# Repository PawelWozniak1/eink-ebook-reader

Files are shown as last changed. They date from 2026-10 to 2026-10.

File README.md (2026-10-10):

# 📖 DIY E-Paper E-Book Reader

🇬🇧 **English** · 🇵🇱 [Polski](README.pl.md)



An e-book reader built from scratch. A Python pipeline prepares the books, firmware with its own page layout engine runs on an ESP32-S3, and the case was designed in OpenSCAD and 3D-printed.

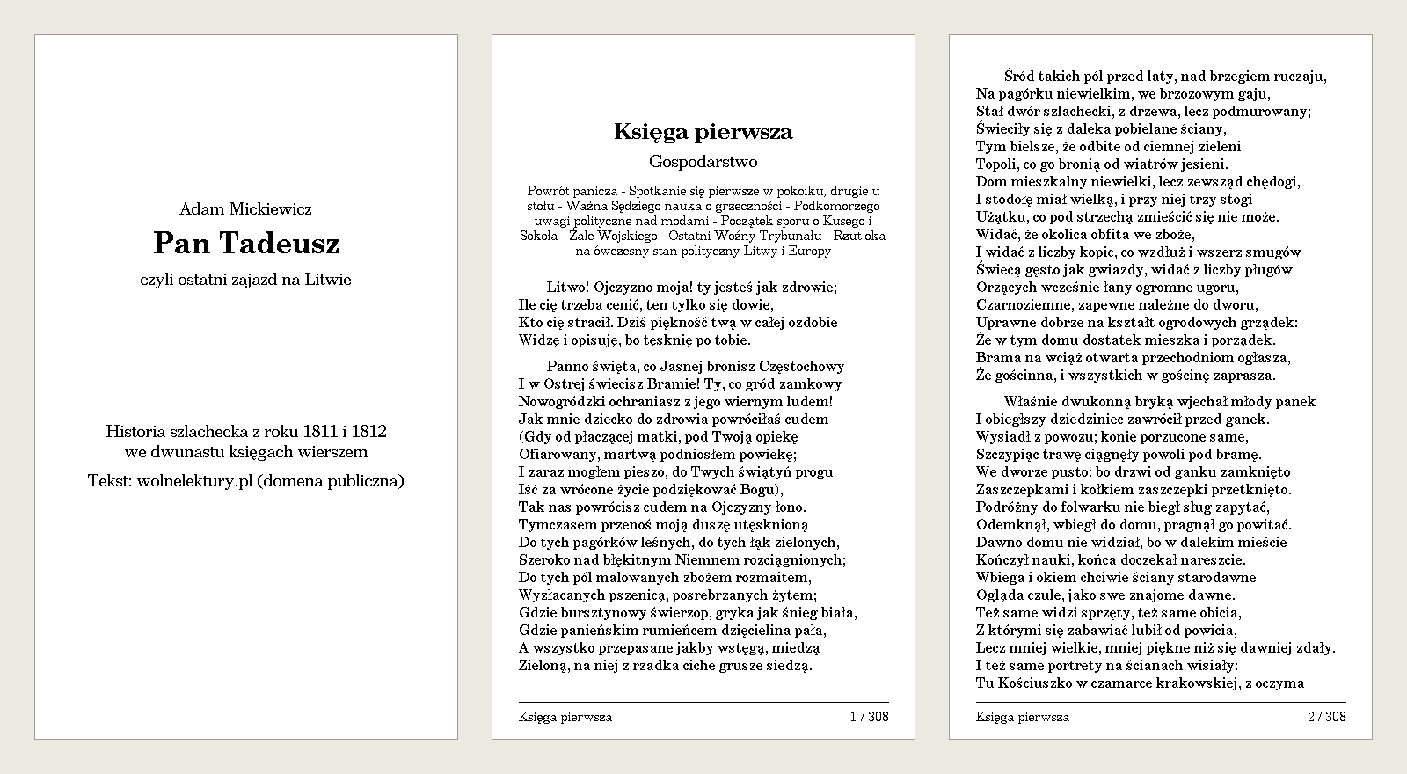
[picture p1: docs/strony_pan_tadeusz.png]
Pages rendered by the simulator


<sub>Pages rendered by the Python simulator with the device's own bitmap fonts: title page, a chapter opening with subtitle and summary, and a regular page with footer.</sub>

---

## ✨ Features

- **Real typesetting:** justified prose paragraphs, indentation, wrapping of over-long verse lines, preserved stanza breaks in poetry
- **Automatic prose vs. poetry detection** based on line-length statistics
- **Chapters and table of contents:** every chapter starts on a new page, navigated with a joystick
- **4 font sizes** with full Polish character support; after a size change the reader stays at the same place in the text
- **Bookmarks:** the reader remembers your position in every book, even after a power cut
- **Power saving:** deep sleep after 30 minutes of inactivity or on a long button press; waking up goes straight back to the last page
- **Battery status** in the library menu: percentage, or a lightning bolt while charging; automatic sleep when the battery runs flat
- **Wi-Fi mode:** a web page for uploading and deleting books and for over-the-air (OTA) firmware updates, no cable needed
- **Captive portal:** with no home network available, the reader starts its own access point and phones open its page automatically
- **Bonus: tic-tac-toe** for two phones, with the board drawn on the e-paper 🎮

---

## 🐍 Python: book preparation pipeline

[`przygotuj_ksiazke.py`](tools/przygotuj_ksiazke.py) ("prepare book") converts raw TXT files from [Wolne Lektury](https://wolnelektury.pl) (a Polish public-domain library) into a lightweight format the reader understands.

```bash
python tools/przygotuj_ksiazke.py
```
```
Pan Tadeusz: 10742 linii, 479913 bajtów -> books/prepared/pan_tadeusz.txt
Treny: 699 linii, 28279 bajtów -> books/prepared/treny.txt
```

What the script does:

| Step | How |
|---|---|
| Strips the license footer | finds the `-----` separator |
| Detects the books (chapters) of *Pan Tadeusz* | a regular expression for "Księga pierwsza … dwunasta" and "Epilog" |
| Tells a chapter subtitle from its summary | heuristic based on line length and indentation |
| Assembles *Treny* from 20 separate files | `pathlib.glob` plus splitting each heading into title and subtitle |
| Generates a title page | a function taking `*args` for any number of subtitles |
| Adapts the text to microcontroller fonts | a replacement table for typographic characters (`—`, `„`, `…`) |
| Normalizes whitespace | collapses blank lines, forces LF line endings, UTF-8 |

Adding a new book takes one entry in the `KSIAZKI` list and a function that returns a list of lines.

The same logic is also ported to JavaScript on the reader's web page ([`strona.h`](firmware/czytnik/strona.h)), so a plain TXT file can be uploaded straight from a phone. The Python script handles the unusual structure of *Pan Tadeusz* and *Treny* better.

### Book file format

The first line is a header. In the text after it, the first byte of each line can be a control marker:

```
#CZYTNIK|Pan Tadeusz|Adam Mickiewicz
\004Pan Tadeusz
\001Księga pierwsza
\002Gospodarstwo
\003Powrót panicza - Spotkanie się pierwsze w pokoiku, drugie u stołu - ...

    Litwo! Ojczyzno moja! ty jesteś jak zdrowie:
```

| Marker | Meaning |
|---|---|
| `\001` | chapter title (always starts a new page) |
| `\002` | chapter subtitle |
| `\003` | chapter summary (smaller font, wrapped) |
| `\004` | large title (title page) |
| `\005` | centered text |
| `\006` | prose paragraph (indented and justified) |
| *(none)* | line of verse |
| empty line | gap between stanzas |

The format is deliberately simple. The reader doesn't have to parse HTML or EPUB, and a single pass over the file is enough to find the chapters and split the text into pages.

---

## 🖥️ Python: reader simulator

[`tools/symulator/`](tools/symulator/) renders a book exactly as the device shows it and saves the pages as PNG files. It is a Python port of the firmware's layout engine, so you can check how a book looks without flashing anything.

```bash
pip install -r requirements.txt
python tools/symulator/czytnik.py books/prepared/pan_tadeusz.txt -s 0 1 2 -m preview.png
```
```
Pan Tadeusz: 308 stron, 13 rozdziałów, wiersz, czcionka średnia
-> preview.png
```

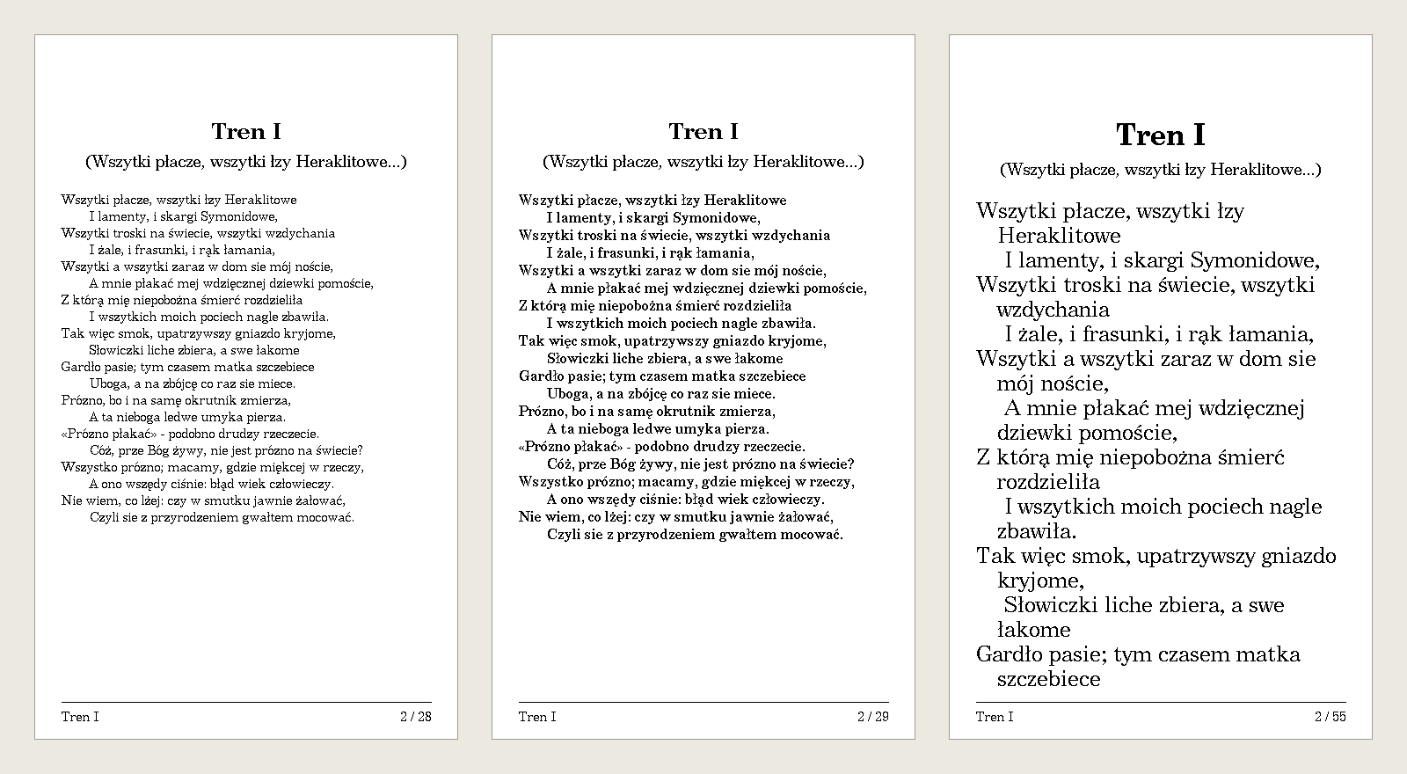
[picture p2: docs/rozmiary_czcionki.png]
The same page at three font sizes


<sub>Tren I at the small, medium and extra-large font sizes. Over-long verse lines wrap with a hanging indent, and the page count in the footer changes with the font size.</sub>

How it works:

- **u8g2 font decoder** ([`u8g2_font.py`](tools/symulator/u8g2_font.py)). The fonts in the firmware are bitmap fonts stored as bit-level run-length encoded byte arrays inside a C source file. The decoder parses C string literals (octal and hex escapes), reads the 23-byte header, finds glyphs via the ASCII lists and the Unicode jump table, and unpacks the RLE bitmaps. Text width follows the library's quirks exactly, e.g. the last glyph counts with its bitmap width, not its advance.
- **Layout engine port** ([`czytnik.py`](tools/symulator/czytnik.py)). The code mirrors `ulozStrone`, `podzielNaStrony` and `rysujStrone` from the firmware and works on UTF-8 byte offsets like the C++ code does. Bookmark positions saved by the device therefore point at the same place in the simulator.
- **CLI** built with `argparse`: pick pages, a font size, an output folder, or a single side-by-side montage.
- **Tests** ([`tests/`](tests/)) run on GitHub Actions. They cover the bit reader, the C literal parser, Polish glyphs in every font, text measurement, and pagination invariants: pages cover the whole text, every chapter starts a new page, and a larger font gives more pages.

The images in this README are generated with `python tools/symulator/zrzuty_do_readme.py`.

---

## 🔌 Firmware

The Arduino code lives in [`firmware/czytnik/`](firmware/czytnik/), about 1,900 lines of C++, HTML and JavaScript:

| File | What's inside |
|---|---|
| [`czytnik.ino`](firmware/czytnik/czytnik.ino) | main loop, buttons, block cache, layout engine, justification, menu, table of contents, bookmarks, deep sleep |
| [`bateria.ino`](firmware/czytnik/bateria.ino) | battery voltage via ADC, percentage from a LiPo discharge curve, charger detection, deep-discharge protection |
| [`siec.ino`](firmware/czytnik/siec.ino) | Wi-Fi (home network or own access point), web server, book upload and delete, firmware upload, ArduinoOTA, captive portal |
| [`strona.h`](firmware/czytnik/strona.h) | the upload web page (HTML/CSS/JS in `PROGMEM`), including the JS port of the book preparation |
| [`gra.ino`](firmware/czytnik/gra.ino) / [`gra.h`](firmware/czytnik/gra.h) | tic-tac-toe for two phones: game state, player slots with timeouts, board drawn on the e-paper |

---

## 🏗️ Architecture

```mermaid
flowchart LR
    WL["Wolne Lektury TXT"] --> PY["przygotuj_ksiazke.py"]
    WL --> JS["reader web page<br/>JS preparation"]
    PY --> TXT["CZYTNIK format"]
    TXT -->|"Wi-Fi upload"| FS[("LittleFS<br/>flash storage")]
    JS --> FS
    FS --> CACHE["block cache 8×4 KB"]
    CACHE --> LAYOUT["page layout engine"]
    LAYOUT --> EPD["7.5 inch e-paper"]
    JOY["joystick + SET/RST"] --> UI["menu / reading / contents"]
    UI --> LAYOUT
    NVS[("Preferences<br/>bookmarks")] <--> UI
```

### Firmware highlights

- **Books larger than RAM:** *Pan Tadeusz* is about 480 KB, so the text is read from flash in 4 KB blocks and the 8 most recently used blocks are kept in an LRU cache.
- **Custom text measurement:** asking the graphics library to measure every word was too slow, so glyph advance widths (up to U+017F, which covers all Polish letters) are computed once and cached for each font.
- **Re-pagination:** when the font size changes, the whole book is split into pages again and the reader returns to the same position in the text, not the same page number.
- **Bookmarks in NVS:** `Preferences` keys are limited to 15 characters, so file names are hashed with FNV-1a. Bookmarks from an older firmware version are migrated automatically.
- **Safe uploads:** an uploaded file is written under a temporary name and only swapped in once complete, so an interrupted upload never corrupts an existing book. File names are sanitized to `a-z0-9_-`.
- **E-paper refresh strategy:** fast partial refresh when turning pages and a full refresh every 20 pages to clear ghosting.

---

## 🔧 Hardware

| Part | Model |
|---|---|
| Microcontroller | ESP32-S3-DevKitC-1 |
| Display | Waveshare e-Paper 7.5" 800×480 (GDEY075T7) + HAT |
| Controls | 5-way joystick + SET + RST |
| Power | LiPo 523450 1000 mAh + TP4056 USB-C charger + Pololu S7V8F3 (3.3 V buck-boost) |

<details>
<summary>Wiring</summary>

| Signal | GPIO |
|---|---|
| e-paper CS / DC / RST / BUSY | 8 / 9 / 10 / 4 |
| e-paper SCK / MOSI | 18 / 17 |
| UP / DWN / LFT / RHT / MID | 5 / 6 / 7 / 15 / 16 |
| SET / RST | 21 / 47 |
| battery voltage (100k/100k divider from TP4056 OUT+) | 1 |
| charger present (100k/100k divider from TP4056 IN+) | 2 |

Buttons pull to GND (internal pull-ups). Newer HATs have a 9th pin, PWR: it goes to 3V3 together with VCC, so the display is always powered.

Power path: battery → TP4056 (B+/B−) → OUT+/OUT− → Pololu S7V8F3 (VIN/GND) → VOUT to the ESP32 **3V3** pin. The 5V pin stays unconnected. Unplug the battery before flashing over USB.

The battery dividers are optional: without them the reader works, it just doesn't show the battery level. How to build them (in Polish): [`docs/dzielnik_baterii.md`](docs/dzielnik_baterii.md).
</details>

<details>
<summary>Layout inside the case</summary>

The reader is held in portrait. Positions are given from the front, as you look at the text:

| Part | Where |
|---|---|
| joystick (with SET and RST) | in the back cover, top left, stick facing out |
| TP4056 | right edge, top, USB-C port in the right wall |
| Pololu converter | lying flat below the charger, pins towards the middle |
| battery | top, between the joystick and the charger |
| HAT | right edge, level with the FPC ribbon (middle of the panel's right edge) |
| ESP32 | bottom centre, USB ports in the bottom wall, antenna up |
| dividers | on a small board right next to GPIO1 and GPIO2 |

The button wires run down the left edge as one bundle and pass under the ESP board to its right header, so the ESP sits on its headers with 2–3 mm of clearance. Routing rules and the full connection table (in Polish): [`docs/okablowanie.md`](docs/okablowanie.md).
</details>

### Wiring

Front view, reader in portrait, display drawn as if transparent. Routing rules and the connection table (in Polish): [`docs/okablowanie.md`](docs/okablowanie.md).

<p align="center">Board and wire layout, front view</p>

### Controls

| Button | Reading | Menu | Contents |
|---|---|---|---|
| UP / DWN | previous / next page | select book | select chapter |
| LFT | chapter start / previous chapter | last read book | back |
| RHT | next chapter | open | go to |
| MID | menu (hold: sleep) | open | go to |
| SET | table of contents | — | back |
| RST | font size | — | — |

---

## 🖨️ Case

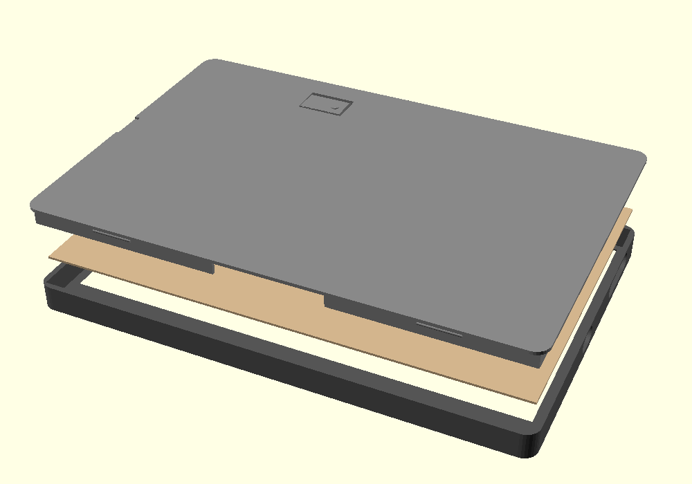
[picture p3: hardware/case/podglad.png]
Case preview (exploded view)


A parametric OpenSCAD design: [`czytnik_eink.scad`](hardware/case/czytnik_eink.scad). Every dimension is a variable: panel size, tolerances, positions of the battery, ESP32 and charger, the USB-C ports and the rear button. That makes it easy to adapt the case to a different display.

It prints as three parts: the front bezel, a support plate behind the panel and the back cover. Ready-made STL and OBJ files are included.

> The case design still follows the earlier electronics layout. The new one (joystick in the back cover, charging port in the right wall, ESP at the bottom) is described in [`docs/okablowanie.md`](docs/okablowanie.md).

---

## 🚀 Getting started

1. **Arduino IDE** with ESP32 support and the `GxEPD2` and `U8g2_for_Adafruit_GFX` libraries.
2. Board: *ESP32S3 Dev Module*. Pick a **Partition Scheme** with OTA and SPIFFS, e.g. *Default 4MB with spiffs (1.2MB APP/1.5MB SPIFFS)*.
3. Flash the sketch from [`firmware/czytnik/`](firmware/czytnik/).
4. Prepare the books: `python tools/przygotuj_ksiazke.py`. Optionally preview them with the simulator.
5. On the reader, choose **Wgraj książki (WiFi)** ("Upload books"), open the address shown on screen (or `http://czytnik.local`) and upload the files from `books/prepared/`.

Later firmware versions can be uploaded through the same page (a `.bin` file) or from the Arduino IDE over the network port.

---

## 📁 Project structure

```
├── books/
│   ├── source/                    # input: Wolne Lektury TXT (Pan Tadeusz, 20 Treny files)
│   └── prepared/                  # output: #CZYTNIK format, ready to upload
├── tools/
│   ├── przygotuj_ksiazke.py       # Python: source TXT -> reader format
│   ├── okablowanie.py             # generates docs/okablowanie.svg and .md
│   └── symulator/
│       ├── czytnik.py             # layout engine port + CLI
│       ├── u8g2_font.py           # u8g2 bitmap font decoder
│       ├── fonty/                 # the 6 fonts used by the firmware
│       └── zrzuty_do_readme.py    # regenerates docs/*.png
├── firmware/czytnik/              # Arduino sketch (open czytnik.ino)
│   ├── czytnik.ino                # main program: layout, menu, bookmarks, sleep
│   ├── bateria.ino                # battery and charging status
│   ├── siec.ino                   # Wi-Fi, web server, uploads, OTA, captive portal
│   ├── strona.h                   # web page (HTML/CSS/JS in PROGMEM)
│   └── gra.ino / gra.h            # tic-tac-toe
├── hardware/case/                 # OpenSCAD source, preview, stl/, obj/
├── tests/                         # unittest, run on GitHub Actions
└── docs/                          # README images, wiring drawing, divider guide
```

The code and its comments are in Polish.

---

## 🛠️ Tech stack

**Python** (pathlib, re, Pillow, argparse, dataclasses, unittest) · **GitHub Actions** · **C++ / Arduino** (ESP32-S3, LittleFS, NVS, deep sleep) · **GxEPD2, U8g2** · **HTML / CSS / JavaScript** · **WebServer, DNSServer, mDNS, ArduinoOTA** · **OpenSCAD** · 3D printing

## 📜 License and sources

The texts of *Pan Tadeusz* (Adam Mickiewicz) and *Treny* (Jan Kochanowski) come from [Wolne Lektury](https://wolnelektury.pl) and are in the public domain.

The bitmap fonts in `tools/symulator/fonty/` come from the [u8g2](https://github.com/olikraus/u8g2) project, which redistributes them under their original X11/Adobe licenses.

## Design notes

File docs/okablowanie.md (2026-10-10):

# Okablowanie i rozmieszczenie płytek

Czytnik w pionie, widok od przodu, tak jak patrzysz na tekst. Ekran jest narysowany jak przezroczysty, więc widać przez niego płytki leżące za nim. Przy składaniu od tyłu lewa i prawa strona się zamieniają. Skala: 1 jednostka = 1 mm.

Rozmieszczenie płytek i przewodów

Wymiary płytek są rzeczywiste: ekran 111×170 mm, ESP32-S3-DevKitC-1 25,5×63 mm, HAT 30×65 mm, LiPo 523450 34×50 mm, TP4056 17×28 mm, Pololu S7V8F3 11,4×15,2 mm. Wnętrze obudowy: ok. 115×174 mm. Kolejność pinów na module joysticka i padów na TP4056 zależy od wersji płytki, więc sprawdź napisy na swoich.

## Zasady prowadzenia przewodów

Numery odpowiadają znacznikom na rysunku.

1. **Gniazdo ładowania w prawej ściance, u góry.** TP4056 leży poziomo, gniazdem USB-C równo ze ścianką. Pod nim, między ładowarką a HAT-em, leży przetwornica, pinami w stronę środka. Przewody z niej schodzą szczeliną między baterią a HAT-em. Jeśli chcesz widzieć diodę ładowania, zrób przy gnieździe mały otwór.
2. **ESP na dole, antena do góry.** Gniazda USB ESP są przy dolnej ściance. Możesz zrobić otwór na gniazdo UART i wgrywać program kablem bez rozkręcania, ale zawsze najpierw odłącz baterię. Który port jest który, sprawdź po napisach na płytce. Nad anteną nie prowadź przewodów.
3. **Bateria osobno, z luzem.** Podłóż i przykryj ją taśmą kaptonową. Mocuj taśmą dwustronną, nie klejem na gorąco. Zostaw 1–2 mm luzu, bo LiPo lekko puchnie z wiekiem.
4. **Taśmę FPC zaginaj łagodnie.** Wychodzi ze środka prawej krawędzi matrycy i wraca na tył do HAT-a, którego środek jest na tej samej wysokości. Zrób łuk, nie ostre zagięcie.
5. **Dzielniki przy samym ESP.** Krótkie mają być przewody do GPIO1 i GPIO2, a długie mogą być wejścia z TP4056. Jak zbudować płytkę: [dzielnik_baterii.md](dzielnik_baterii.md).
6. **Przyciski jednym pasem wzdłuż lewej krawędzi.** SET, RST i COM dochodzą do lewej listwy ESP, a pięć kierunków przechodzi pod płytką ESP do prawej listwy (na rysunku przyciemnione). ESP stoi więc na listwach z 2–3 mm prześwitu. Białe znaczniki to miejsca na opaskę albo kroplę kleju.
7. **Joystick w tylnej klapce.** Moduł przyklej albo przykręć od środka, grzybkiem na zewnątrz, i wytnij otwór trochę większy od grzybka. Na SET i RST zrób małe otwory albo naciskaj je wykałaczką. Piny są na krótszej krawędzi modułu, ułóż ją w dół.

## Przewody

- **Zasilanie** (bateria → TP4056 → Pololu → ESP): silikonowy 24 AWG. Przy nadawaniu Wi-Fi ESP32 pobiera chwilowo ok. 0,5 A.
- **Sygnały** (przyciski, dzielniki): silikonowy 28–30 AWG albo kynar.
- **Ekran:** oryginalny kabelek PH2.0 z HAT-a, od strony ESP obcięty i przylutowany. Wtyczki Dupont dodają ok. 10 mm wysokości.

## Tabela połączeń

| Skąd | Dokąd | Uwagi |
|---|---|---|
| **Zasilanie** | | |
| bateria + | TP4056 B+ |  |
| bateria − | TP4056 B− |  |
| TP4056 OUT+ | Pololu VIN |  |
| TP4056 OUT− | Pololu GND | masa całego układu to OUT−, nie B− |
| Pololu VOUT | ESP 3V3 | nie do pinu 5V |
| Pololu GND | ESP GND | skręć razem z przewodem 3V3 |
| **Pomiar baterii (opcjonalny)** | | |
| TP4056 OUT+ | dzielnik baterii | drugi przewód na ten sam pad OUT+ |
| TP4056 IN+ (5 V z USB) | dzielnik ładowarki | pad przy gnieździe USB-C |
| dzielnik baterii | GPIO1 |  |
| dzielnik ładowarki | GPIO2 |  |
| masa dzielników | ESP GND | ten sam pin GND co przetwornica |
| **Ekran (kabelek z HAT-a)** | | |
| HAT VCC | ESP GPIO3V3 |  |
| HAT GND | ESP GND |  |
| HAT DIN | ESP GPIO17 |  |
| HAT CLK | ESP GPIO18 |  |
| HAT CS | ESP GPIO8 |  |
| HAT DC | ESP GPIO9 |  |
| HAT RST | ESP GPIO10 |  |
| HAT BUSY | ESP GPIO4 |  |
| HAT PWR | ESP GPIO3V3 |  |
| **Przyciski (joystick w tylnej klapce)** | | |
| COM | ESP GND | wspólny przewód wszystkich przycisków |
| SET | ESP GPIO21 |  |
| RST | ESP GPIO47 |  |
| MID | ESP GPIO16 |  |
| RHT | ESP GPIO15 |  |
| LFT | ESP GPIO7 |  |
| DWN | ESP GPIO6 |  |
| UP | ESP GPIO5 |  |

---

Rysunek i ta strona są generowane przez [`tools/okablowanie.py`](../tools/okablowanie.py). Po zmianie układu uruchom `python tools/okablowanie.py`.

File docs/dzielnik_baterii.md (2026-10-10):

# Dzielnik napięcia do pomiaru baterii

Bez tej płytki czytnik działa normalnie, tylko nie pokazuje stanu baterii. Z nią w menu biblioteki widać procent naładowania albo błyskawicę podczas ładowania, a przy rozładowanej baterii (ok. 3,3 V) czytnik sam się usypia. Kod jest w [`firmware/czytnik/bateria.ino`](../firmware/czytnik/bateria.ino).

## Po co dzielnik

Bateria ma do 4,2 V, a USB 5 V. Wejście ADC w ESP32-S3 przyjmuje maksymalnie ok. 3,1 V, więc napięcie trzeba podzielić na pół. Robią to dwa jednakowe rezystory połączone szeregowo.

```
   wejście
      │
    [100k]   górny
      │
      ├──────► GPIO        połowa napięcia
      │
    [100k]   dolny
      │
     GND
```

Potrzebne są dwa takie dzielniki:

| Dzielnik | Wejście | Wyjście | Co mierzy |
|---|---|---|---|
| bateria | TP4056 **OUT+** | **GPIO1** | napięcie baterii (1,6–2,1 V na pinie) |
| ładowarka | TP4056 **IN+** (5 V z USB) | **GPIO2** | czy ładowarka jest wpięta (ok. 2,5 V albo 0 V) |

## Części

- 4 rezystory 100 kΩ, 1/4 W, THT. Pasuje też inna wartość w zakresie ok. 47k–470k, byle w parze były dwie jednakowe sztuki. Przy rezystorach 5% kup 8 sztuk i dobierz pary multimetrem.
- Kondensator ceramiczny 100 nF (nadruk `104`), uspokaja odczyt ADC.
- Kawałek płytki uniwersalnej, raster 2,54 mm, ok. 2×2 cm (najlepiej dwustronnej, z metalizowanymi otworami).

Nie używaj 1 kΩ ani innych małych wartości. Dzielnik baterii pobiera prąd cały czas, także w uśpieniu: 2×100 kΩ to ok. 20 µA, a 2×1 kΩ to ok. 2 mA, które rozładowałyby baterię w kilka tygodni.

## Ułożenie na płytce

```
   5V (z IN+)          VBAT (z OUT+)
       │                    │
     [R3]                 [R1]
       │                    │
       ●──┐              ┌──●──[C]──┐
       │  │              │  │       │
     [R4] │              │ [R2]     │
       │  │              │  │       │
   ····●··│··············│··●·······●···· GND (od spodu płytki) ──► GND ESP
          ▼              ▼
        GPIO2          GPIO1
```

1. Wlutuj R1 nad R2 i R3 nad R4, w dwóch kolumnach. Wspólna nóżka w każdej parze to środek dzielnika.
2. Kondensator wlutuj między środek dzielnika baterii (R1/R2) a masę. Nie ma polaryzacji.
3. Dolne końce R2, R4 i kondensatora połącz razem jako masę. Poprowadź ją od spodu płytki, wtedy nie krzyżuje się z odczepami do GPIO.
4. Płytkę przyklej tuż obok pinów 1 i 2 ESP. Przewody do GPIO mają być krótkie, bo rezystory 100 kΩ mają dużą impedancję i długi przewód zbiera zakłócenia. Długie mogą być przewody wejściowe z TP4056.

## Sprawdzenie przed podłączeniem do ESP

Najpierw przylutuj tylko wejścia i masę, a przewodów do GPIO jeszcze nie. Zmierz multimetrem względem GND:

- środek R1/R2: połowa napięcia baterii, czyli ok. 1,6–2,1 V,
- środek R3/R4: ok. 2,5 V przy wpiętej ładowarce, 0 V bez niej.

Jeśli zobaczysz ok. 4 V albo 5 V, coś jest źle połączone. Takie napięcie spali pin ESP, więc najpierw znajdź błąd. Gdy wartości się zgadzają, dolutuj przewody do GPIO1 i GPIO2.

## Pierwsze uruchomienie

Wgraj program i wejdź do menu. Obok napisu „Biblioteka” powinna być ikona baterii z procentem. Po wpięciu ładowarki ekran sam się odświeży i pojawi się błyskawica z napisem `ładuje`, a po naładowaniu `pełna`.

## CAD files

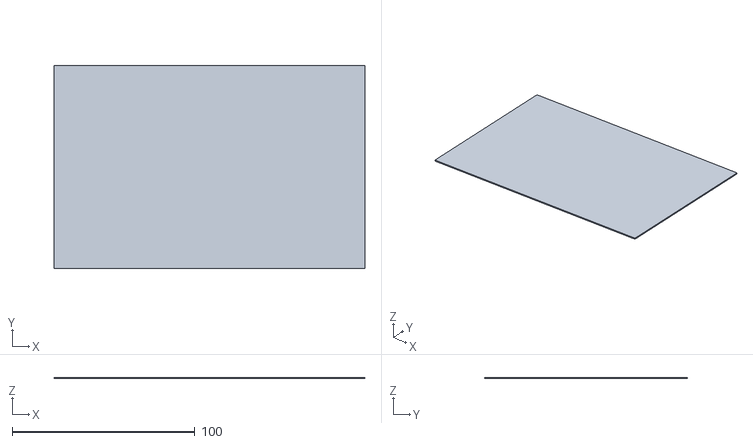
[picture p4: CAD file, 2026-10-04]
hardware/case/stl/czytnik_plytka.stl
170.0 x 111.0 x 0.8

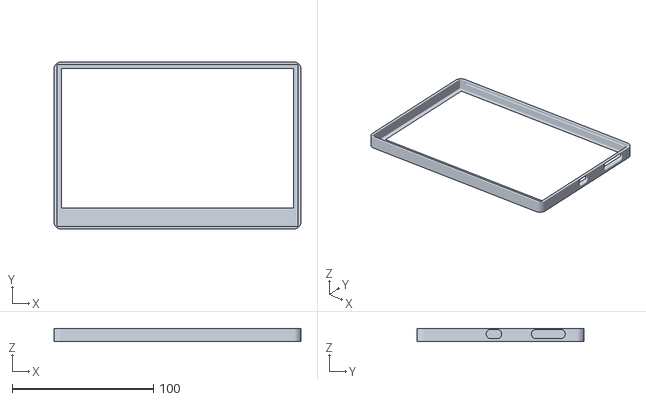
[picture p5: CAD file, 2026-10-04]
hardware/case/stl/czytnik_przod.stl
174.8 x 118.3 x 9.40

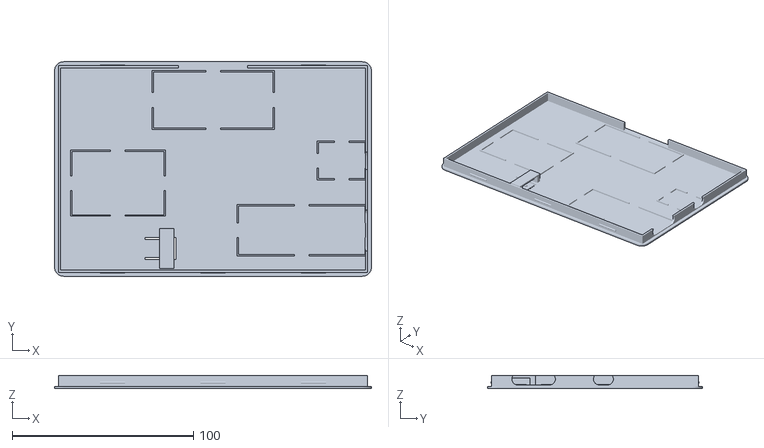
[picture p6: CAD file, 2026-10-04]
hardware/case/stl/czytnik_klapka.stl
174.8 x 118.3 x 7.20

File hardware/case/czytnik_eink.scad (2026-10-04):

// ============================================================
//  Obudowa czytnika DIY  —  e-Paper 7,5" Waveshare 13504 (800x480)
//  ESP32-S3-DevKitC-1, LiPo 523450, TP4056 USB-C, 1 przycisk z tylu
//  Jednostki: mm
//
//  Uklad wspolrzednych: widok OD PRZODU (od strony ekranu),
//  x w prawo, y w gore, z=0 to przednia powierzchnia, z rosnie do tylu.
//  Wszystkie pozycje czesci podajesz wiec tak, jak widzisz je przez ekran.
//
//  Czesci:
//    "front" – przednia ramka ze sciankami (drukuj przodem do stolu)
//    "mid"   – plytka podporowa za panelem (0,8 mm)
//    "lid"   – tylna klapka z rantem, przyciskiem i gniazdami na czesci
//    "all"   – podglad zlozenia,  "exploded" – podglad rozlozony
// ============================================================

part = "exploded"; // [front, mid, lid, all, exploded]

/* [Panel e-ink — ZMIERZ swoj egzemplarz!] */
panel_w   = 170.2;
panel_h   = 111.2;
panel_t   = 1.2;
aa_w      = 163.2;   // obszar aktywny
aa_h      = 97.92;
aa_left   = 3.5;     // od lewej krawedzi panelu do obszaru aktywnego
aa_bottom = 10.58;   // od dolnej krawedzi (strona tasmy FPC) do obszaru aktywnego
fpc_center_x = 85.1; // srodek tasmy FPC liczony od lewej krawedzi panelu
fpc_w     = 32;      // szerokosc tasmy + zapas

/* [Obudowa] */
wall      = 2.0;   // grubosc scianek bocznych
clr       = 0.3;   // luz wokol panelu
fpc_gap   = 2.5;   // dodatkowe miejsce na zagiecie tasmy FPC (dol)
front_t   = 1.2;   // grubosc przodu (ramki)
pocket_t  = 1.4;   // gniazdo na panel (panel 1,2 + luz)
mid_t     = 0.8;   // plytka podporowa
cav       = 6.0;   // wysokosc komory na elektronike
back_t    = 1.2;   // tylna scianka
corner_r  = 5;
fit       = 0.15;  // luz pasowania rantu klapki
rim_t     = 1.2;   // grubosc rantu klapki
win_margin= 0.4;   // okno troche wieksze niz obszar aktywny
bevel     = 1.0;   // fazowanie okna od przodu

/* [Przycisk z tylu] */
btn_x0    = 50;    // poczatek klawisza (zawias) — x
btn_cy    = 103;   // srodek klawisza — y
btn_len   = 16;
btn_w     = 10;
slot      = 1.0;   // szerokosc szczeliny wokol klawisza
sw_h      = 4.3;   // wysokosc tact switcha z popychaczem (6x6x4.3)
sw_size   = 6.2;

/* [Polozenie czesci (lewy dolny rog, widok od przodu)] */
hat_pos = [55, 6];    hat_size = [65, 30.2];
bat_pos = [10, 50];   bat_size = [50, 34];
tp_size = [25, 19];
esp_size= [69, 26];

$fn = 32;

// ---------- wartosci wyliczone ----------
iw = panel_w + 2*clr;
ih = panel_h + 2*clr + fpc_gap;
W  = iw + 2*wall;
H  = ih + 2*wall;
px = wall + clr;                 // panel – lewy dolny rog
py = wall + clr + fpc_gap;
z_mid = front_t + pocket_t;
z_cav = z_mid + mid_t;
z_lid = z_cav + cav;
T     = z_lid + back_t;
rim_in = wall + fit + rim_t;     // wewnetrzna krawedz rantu

esp_pos = [W - rim_in - 0.5 - esp_size[0], 80];
tp_pos  = [W - rim_in - 0.5 - tp_size[0], 45];

port_z  = 5.4;   // wysokosc srodka gniazd USB-C (od przodu)
ports = [ // [srodek y, dlugosc, wysokosc]
  [esp_pos[1] + esp_size[1]/2, 24, 6.5],   // ESP32 (oba gniazda)
  [tp_pos[1]  + tp_size[1]/2,  11, 6.5]    // TP4056
];

z_snap = z_cav + cav*0.65;

// przycisk – mostek z przelacznikiem
sw_x   = btn_x0 + btn_len - 4;
cb_z0  = z_cav + 0.1;
cb_z1  = cb_z0 + 1.2;
sw_tip = cb_z1 - 0.6 + sw_h;
pin_l  = z_lid - sw_tip - 0.2;
assert(pin_l >= 0.3, "Przelacznik za wysoki: zmniejsz sw_h albo zwieksz cav");
echo(str("Wymiary zewnetrzne: ", W, " x ", H, " x ", T, " mm"));
echo(str("Dlugosc popychacza: ", pin_l, " mm"));

// ---------- pomocnicze ----------
module rbox(x, y, w, h, r, z0, z1)
  translate([x, y, z0]) linear_extrude(z1 - z0)
    offset(r) offset(-r) square([w, h]);

module port_cuts() {
  for (p = ports) {
    yc = p[0]; l = p[1]; hh = p[2];
    hull() for (s = [-1, 1])
      translate([W - rim_in - 1, yc + s*(l - hh)/2, port_z])
        rotate([0, 90, 0]) cylinder(d = hh, h = rim_in + 2);
  }
}

module locator(pos, size, h = 1.0, t = 0.8, c = 0.4, gap = 8) {
  difference() {
    translate([pos[0]-c-t, pos[1]-c-t, z_lid-h])
      cube([size[0]+2*(c+t), size[1]+2*(c+t), h]);
    translate([pos[0]-c, pos[1]-c, z_lid-h-1])
      cube([size[0]+2*c, size[1]+2*c, h+2]);
    // przerwy na kable w polowie bokow
    translate([pos[0]+size[0]/2-gap/2, pos[1]-c-t-1, z_lid-h-1]) cube([gap, size[1]+2*(c+t)+2, h+2]);
    translate([pos[0]-c-t-1, pos[1]+size[1]/2-gap/2, z_lid-h-1]) cube([size[0]+2*(c+t)+2, gap, h+2]);
  }
}

// ---------- PRZOD ----------
module front() {
  wx = px + aa_left - win_margin;
  wy = py + aa_bottom - win_margin;
  ww = aa_w + 2*win_margin;
  wh = aa_h + 2*win_margin;
  difference() {
    rbox(0, 0, W, H, corner_r, 0, z_lid);
    translate([wall, wall, front_t]) cube([iw, ih, z_lid]);
    // okno z fazowaniem
    hull() {
      translate([wx, wy, front_t - 0.01]) cube([ww, wh, 0.1]);
      translate([wx - bevel, wy - bevel, -0.01]) cube([ww + 2*bevel, wh + 2*bevel, 0.01]);
    }
    // rowki zatrzaskow
    for (y = [wall, H - wall])
      translate([wall + 5, y, z_snap]) rotate([0, 90, 0]) cylinder(r = 0.65, h = iw - 10);
    port_cuts();
  }
}

// ---------- PLYTKA PODPOROWA ----------
module mid() {
  translate([px + 0.1, py + 0.1, z_mid]) cube([panel_w - 0.2, panel_h - 0.2, mid_t]);
}

// ---------- TYLNA KLAPKA ----------
module lid() {
  difference() {
    union() {
      // dno
      rbox(0, 0, W, H, corner_r, z_lid, T);
      // rant
      difference() {
        translate([wall + fit, wall + fit, z_cav]) cube([iw - 2*fit, ih - 2*fit, cav + 0.01]);
        translate([rim_in, rim_in, z_cav - 1]) cube([W - 2*rim_in, H - 2*rim_in, cav + 2]);
        // wyciecie na tasme FPC
        translate([px + fpc_center_x - (fpc_w + 6)/2, wall - 1, z_cav - 1])
          cube([fpc_w + 6, rim_t + fit + 2, cav + 1]);
      }
      // zatrzaski
      for (x = [25, W - 25 - 14])
        translate([x, wall + fit + 0.15, z_snap]) rotate([0, 90, 0]) cylinder(r = 0.6, h = 14);
      for (x = [25, W/2 - 7, W - 25 - 14])
        translate([x, H - wall - fit - 0.15, z_snap]) rotate([0, 90, 0]) cylinder(r = 0.6, h = 14);
      // gniazda na czesci
      locator(hat_pos, hat_size);
      locator(bat_pos, bat_size);
      locator(esp_pos, esp_size);
      locator(tp_pos,  tp_size);
      // mostek z przelacznikiem
      for (s = [-1, 1])
        translate([sw_x - 4, btn_cy + s*(btn_w/2 + slot + 3.5) - 1.5, cb_z0])
          cube([8, 3, z_lid - cb_z0]);
      translate([sw_x - 4, btn_cy - btn_w/2 - slot - 5, cb_z0])
        cube([8, btn_w + 2*slot + 10, cb_z1 - cb_z0]);
    }
    // szczelina w ksztalcie U wokol klawisza
    difference() {
      translate([btn_x0, btn_cy - btn_w/2 - slot, z_lid - 1])
        cube([btn_len + slot, btn_w + 2*slot, back_t + 2]);
      translate([btn_x0 - 1, btn_cy - btn_w/2, z_lid - 2])
        cube([btn_len + 1, btn_w, back_t + 4]);
    }
    // klawisz lekko wpuszczony (cienszy = latwiej sie ugina)
    translate([btn_x0, btn_cy - btn_w/2, T - 0.4]) cube([btn_len, btn_w, 1]);
    // gniazdo na przelacznik w mostku
    translate([sw_x - sw_size/2, btn_cy - sw_size/2, cb_z1 - 0.6]) cube([sw_size, sw_size, 1]);
    // otwory USB
    port_cuts();
    // wciecie do podwazania klapki
    translate([-1, H/2 - 6, T - 0.8]) cube([3, 12, 1]);
  }
  // popychacz + wyczuwalna kropka
  translate([sw_x, btn_cy, z_lid - pin_l]) cylinder(d = 3, h = pin_l + 0.01);
  translate([sw_x, btn_cy, T - 0.41]) cylinder(d = 3, h = 0.3);
}

// ---------- wybor ----------
if (part == "front") front();
else if (part == "mid") translate([0, 0, -z_mid]) mid();
else if (part == "lid") translate([0, H, T]) rotate([180, 0, 0]) lid(); // dnem do stolu
else if (part == "all") { color("#555") front(); color("tan") mid(); color("#888") lid(); }
else {
  color("#555") front();
  color("tan") translate([0, 0, 15]) mid();
  color("#888") translate([0, 0, 30]) lid();
}

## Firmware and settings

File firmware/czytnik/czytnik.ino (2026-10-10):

// Czytnik książek na e-papierze 7,5" + joystick
//
// Joystick (COM do GND), podczas czytania:
//   UP     - poprzednia strona
//   DWN    - następna strona
//   LFT    - początek rozdziału / poprzedni rozdział
//   RHT    - następny rozdział
//   MID    - menu z listą książek
//   MID przytrzymany - wyczyść ekran i uśpij (potem można odłączyć zasilanie)
//   SET    - spis treści
//   RST    - wielkość czcionki (mała / średnia / duża / bardzo duża)
//
// W spisie treści:
//   UP/DWN - wybór rozdziału
//   MID/RHT - przejdź do rozdziału
//   SET/LFT - wróć do czytania
//
// W menu:
//   UP/DWN - wybór książki
//   MID/RHT - otwórz książkę (ostatnia pozycja: tryb WiFi)
//   LFT    - wróć do ostatnio czytanej
//
// Po USPIJ_PO bez naciskania przycisków czytnik sam czyści ekran i zasypia.
// MID budzi go i otwiera książkę w tym samym miejscu.
//
// Książki są plikami w pamięci flash (LittleFS, katalog /k). Wgrywa się je przez WiFi:
// w menu wybierz "Wgraj książki (WiFi)" i otwórz w przeglądarce adres pokazany na ekranie.
// Tam można też wgrać nowy program (.bin) bez kabla. Kod WiFi jest w siec.ino.
//
// Stan baterii i ładowanie widać w menu (bateria.ino).
//
// Arduino IDE: Narzędzia > Partition Scheme musi mieć OTA i SPIFFS (tam trafia LittleFS),
// np. "Default 4MB with spiffs (1.2MB APP/1.5MB SPIFFS)". Schematy z FATFS albo "No OTA" nie zadziałają.

#include <GxEPD2_BW.h>
#include <U8g2_for_Adafruit_GFX.h>
#include <Preferences.h>
#include <LittleFS.h>
#include <vector>
#include <algorithm>
#include <driver/rtc_io.h>

// jeśli nie działa, wróć do starego sterownika: zamień oba GxEPD2_750_GDEY075T7 na GxEPD2_750_T7
GxEPD2_BW<GxEPD2_750_GDEY075T7, GxEPD2_750_GDEY075T7::HEIGHT> display(
  GxEPD2_750_GDEY075T7(/*CS=*/ 8, /*DC=*/ 9, /*RST=*/ 10, /*BUSY=*/ 4)
);
const char* WERSJA = "6 (bateria)";  // pokazywana w trybie WiFi i na stronie

U8G2_FOR_ADAFRUIT_GFX u8g2Fonts;
Preferences pamiec;

// --- przyciski ---
enum { GORA, DOL, LEWO, PRAWO, SRODEK, SET_, RST_, ILE_PRZYCISKOW };
const int pinyPrzyciskow[ILE_PRZYCISKOW] = {5, 6, 7, 15, 16, 21, 47};
const char* nazwyPrzyciskow[ILE_PRZYCISKOW] = {"UP", "DWN", "LFT", "RHT", "MID", "SET", "RST"};
bool byloWcisniete[ILE_PRZYCISKOW];
unsigned long wcisnietyOd[ILE_PRZYCISKOW];  // 0 = wciśnięcia nie widzieliśmy (np. trzymany przy starcie)
unsigned long ostatniaAktywnosc = 0;

// --- usypianie ---
const unsigned long DLUGIE_WCISNIECIE = 1500;          // ms przytrzymania MID, żeby uśpić
const unsigned long USPIJ_PO = 30UL * 60 * 1000;       // samo zasypia po 30 min bez przycisków

// --- układ strony (ekran pionowo 480 x 800) ---
const int MARGINES = 30;           // lewy margines
const int MARGINES_PRAWY = 30;     // prawy margines
const int GORA_TEKSTU = 40;        // gdzie zaczyna się tekst
const int MIEJSCE_NA_STOPKE = 52;  // wysokość stopki na dole
const int WCIECIE_SPACJI = 8;      // ile pikseli na jedną spację wcięcia
const int WCIECIE_ZAWINIECIA = 24; // wcięcie dalszej części zbyt długiego wersu
const int WCIECIE_AKAPITU = 24;    // wcięcie pierwszej linii akapitu prozy
const int PELNE_ODSWIEZENIE_CO = 20; // co ile stron pełne odświeżenie

// znaczniki z przygotuj_ksiazke.py (i ze strony w trybie WiFi)
// T_ZWYKLY to wers wiersza, T_AKAPIT to akapit prozy (wcięty i wyjustowany)
const char T_ZWYKLY = 0, T_KSIEGA = 1, T_PODTYTUL = 2, T_STRESZCZENIE = 3, T_TYTUL = 4, T_SRODEK = 5,
           T_AKAPIT = 6;

// --- książki w pamięci flash ---
// pierwsza linia pliku: #CZYTNIK|tytuł|autor, dalej tekst ze znacznikami
const char* NAGLOWEK = "#CZYTNIK|";

struct Ksiazka {
  String plik;       // nazwa pliku w /k
  String tytul;
  String autor;
  uint32_t dlugosc;  // długość tekstu (bez nagłówka)
};
std::vector<Ksiazka> ksiazki;

// co jest na ekranie
enum Ekran { CZYTANIE, MENU, WIFI, SPIS };
Ekran ekran = MENU;

// otwarta książka
int otwarta = -1;          // numer w 'ksiazki', -1 = żadna nie jest wczytana
String otwartyPlik;        // ostatnio czytana (zostaje też po zamknięciu)
File plikKsiazki;
uint32_t poczatekTekstu = 0;  // gdzie w pliku zaczyna się tekst (za nagłówkiem)
uint32_t DLUGOSC = 0;
bool proza = false;        // true = książka prozą (akapity), false = wierszem (wersy)
int dolTekstu;

std::vector<uint32_t> strony;          // gdzie w tekście zaczyna się każda strona
std::vector<uint32_t> ksiegi;          // gdzie w tekście zaczyna się każdy rozdział
std::vector<int> pierwszaStronaKsiegi; // numer strony, od której zaczyna się każdy rozdział
int obecna = 0;
int odswiezenOdPelnego = 0;

// menu
int wybrana = 0;
const int NA_EKRANIE = 6;  // ile pozycji menu mieści się na ekranie

// spis treści
int wybranyRozdzial = 0;
const int NA_EKRANIE_SPISU = 15;
const int WYS_SPISU = 42;  // wysokość pozycji w spisie

// wielkość czcionki (zapamiętywana, RST zmienia)
const uint8_t* const CZCIONKI_TEKSTU[] = {u8g2_font_ncenR10_te, u8g2_font_ncenR12_te,
                                          u8g2_font_ncenR14_te, u8g2_font_ncenR18_te};
const char* NAZWY_ROZMIAROW[] = {"mała", "średnia", "duża", "bardzo duża"};
const int ILE_ROZMIAROW = 4;
int rozmiar = 1;

// --- czytanie tekstu z pliku ---
// Cała książka nie mieści się w RAM, więc tekst jest czytany kawałkami (blokami),
// a kilka ostatnio używanych bloków trzymamy w pamięci.

const int BLOK = 4096, ILE_BLOKOW = 8;
struct Blok {
  int32_t nr;
  uint32_t uzyty;
  char dane[BLOK];
};
Blok bloki[ILE_BLOKOW];
uint32_t licznikUzyc = 0;

void wyczyscBufor() {
  for (Blok& b : bloki) { b.nr = -1; b.uzyty = 0; }
}

// znak nr 'i' otwartej książki (0 za końcem tekstu)
char znak(uint32_t i) {
  if (i >= DLUGOSC) return '\0';
  int32_t nr = i / BLOK;
  Blok* b = nullptr;
  Blok* najstarszy = &bloki[0];
  for (Blok& x : bloki) {
    if (x.nr == nr) { b = &x; break; }
    if (x.uzyty < najstarszy->uzyty) najstarszy = &x;
  }
  if (!b) {
    b = najstarszy;
    plikKsiazki.seek(poczatekTekstu + (uint32_t)nr * BLOK);
    plikKsiazki.read((uint8_t*)b->dane, BLOK);
    b->nr = nr;
  }
  b->uzyty = ++licznikUzyc;
  return b->dane[i % BLOK];
}

// --- lista książek ---

// czyta pierwszą linię pliku (najwyżej 300 znaków), "" gdy jej brak
String czytajNaglowek(File& f) {
  String s;
  while (f.available() && s.length() < 300) {
    char c = f.read();
    if (c == '\n') return s;
    s += c;
  }
  return "";
}

void wczytajListe() {
  ksiazki.clear();
  File katalog = LittleFS.open("/k");
  if (katalog) {
    for (File f = katalog.openNextFile(); f; f = katalog.openNextFile()) {
      String nazwa = f.name();
      if (f.isDirectory() || nazwa.startsWith(".")) continue;
      String n = czytajNaglowek(f);
      if (!n.startsWith(NAGLOWEK)) continue;
      int kreska = n.indexOf('|', strlen(NAGLOWEK));
      Ksiazka k;
      k.plik = nazwa;
      k.tytul = n.substring(strlen(NAGLOWEK), kreska < 0 ? n.length() : kreska);
      k.autor = kreska < 0 ? "" : n.substring(kreska + 1);
      k.dlugosc = f.size() - n.length() - 1;
      ksiazki.push_back(k);
    }
  }
  std::sort(ksiazki.begin(), ksiazki.end(),
            [](const Ksiazka& a, const Ksiazka& b) { return a.tytul < b.tytul; });
  Serial.printf("Ksiazek: %d\n", (int)ksiazki.size());
}

int indeksPliku(const String& plik) {
  for (int i = 0; i < (int)ksiazki.size(); i++) {
    if (ksiazki[i].plik == plik) return i;
  }
  return -1;
}

void zamknijKsiazke() {
  plikKsiazki.close();
  otwarta = -1;
}

// --- tekst ---

// Szerokości liter (o ile przesuwa się kursor) dla każdej czcionki, liczone raz i zapamiętywane.
// Mierzenie tekstu przez bibliotekę przy każdym słowie było bardzo wolne przy długich akapitach.
const int ILE_KODOW = 384;  // do U+017F - wszystkie polskie litery
struct Szerokosci {
  const uint8_t* czcionka;
  int8_t w[ILE_KODOW];  // -1 = jeszcze nie policzone
};
Szerokosci szerokosci[10];
int ileSzerokosci = 0;
const uint8_t* biezacaCzcionka = nullptr;
Szerokosci* biezaceSzer = nullptr;

void ustawFont(const uint8_t* f) {
  u8g2Fonts.setFont(f);
  biezacaCzcionka = f;
  biezaceSzer = nullptr;
}

void ustawCzcionke(char typ) {
  switch (typ) {
    case T_KSIEGA:       ustawFont(rozmiar == 3 ? u8g2_font_ncenB24_te : u8g2_font_ncenB18_te); break;
    case T_PODTYTUL:     ustawFont(u8g2_font_ncenR14_te); break;
    case T_STRESZCZENIE: ustawFont(rozmiar >= 2 ? u8g2_font_ncenR12_te : u8g2_font_ncenR10_te); break;
    case T_TYTUL:        ustawFont(u8g2_font_ncenB24_te); break;
    case T_SRODEK:       ustawFont(u8g2_font_ncenR14_te); break;
    default:             ustawFont(CZCIONKI_TEKSTU[rozmiar]); break;
  }
}

// zapisuje znak 'kod' w UTF-8, zwraca liczbę bajtów
int doUtf8(uint16_t kod, char* s) {
  if (kod < 0x80) { s[0] = kod; return 1; }
  if (kod < 0x800) { s[0] = 0xC0 | (kod >> 6); s[1] = 0x80 | (kod & 0x3F); return 2; }
  s[0] = 0xE0 | (kod >> 12); s[1] = 0x80 | ((kod >> 6) & 0x3F); s[2] = 0x80 | (kod & 0x3F);
  return 3;
}

// o ile pikseli przesuwa się tekst po znaku 'kod' w bieżącej czcionce
int przesuniecie(uint16_t kod) {
  // szerokość "Xl" minus "l" to dokładnie przesunięcie po X (biblioteka poprawia tylko ostatnią literę)
  auto zmierz = [](uint16_t k) {
    char s[5];
    int n = doUtf8(k, s);
    s[n] = 'l';
    s[n + 1] = '\0';
    return u8g2Fonts.getUTF8Width(s) - u8g2Fonts.getUTF8Width("l");
  };
  if (kod >= ILE_KODOW) return zmierz(kod);
  if (!biezaceSzer) {
    for (int i = 0; i < ileSzerokosci; i++) {
      if (szerokosci[i].czcionka == biezacaCzcionka) biezaceSzer = &szerokosci[i];
    }
    if (!biezaceSzer) {
      biezaceSzer = &szerokosci[ileSzerokosci < 10 ? ileSzerokosci++ : 0];
      biezaceSzer->czcionka = biezacaCzcionka;
      memset(biezaceSzer->w, -1, sizeof(biezaceSzer->w));
    }
  }
  if (biezaceSzer->w[kod] < 0) biezaceSzer->w[kod] = zmierz(kod);
  return biezaceSzer->w[kod];
}

// kod znaku UTF-8 zaczynającego się na pozycji 'q', w 'dl' zwraca liczbę bajtów
uint16_t kodZnaku(uint32_t q, int& dl) {
  uint8_t b = znak(q);
  if (b < 0x80) { dl = 1; return b; }
  if ((b & 0xE0) == 0xC0) { dl = 2; return ((b & 0x1F) << 6) | (znak(q + 1) & 0x3F); }
  if ((b & 0xF0) == 0xE0) {
    dl = 3;
    return ((b & 0x0F) << 12) | ((znak(q + 1) & 0x3F) << 6) | (znak(q + 2) & 0x3F);
  }
  dl = 1;
  return '?';
}

// kopiuje kawałek tekstu do bufora, żeby można go było zmierzyć albo narysować
const char* wytnij(uint32_t od, uint32_t doo) {
  static char bufor[1024];
  uint32_t n = min<uint32_t>(doo - od, sizeof(bufor) - 1);
  for (uint32_t i = 0; i < n; i++) bufor[i] = znak(od + i);
  bufor[n] = '\0';
  return bufor;
}

int szerokosc(uint32_t od, uint32_t doo) {
  return u8g2Fonts.getUTF8Width(wytnij(od, doo));
}

// zwraca, gdzie uciąć linię od 'p' do 'koniec', żeby zmieściła się w 'szer' pikselach
uint32_t dopasuj(uint32_t p, uint32_t koniec, int szer) {
  uint32_t ostatniaSpacja = 0;
  int w = 0;  // szerokość tekstu od 'p' do 'q'
  for (uint32_t q = p; q < koniec; ) {
    int dl;
    uint16_t kod = kodZnaku(q, dl);
    if (kod == ' ' && q > p) {
      if (w > szer) break;
      ostatniaSpacja = q;
    }
    w += przesuniecie(kod);
    q += dl;
  }
  if (w <= szer) return koniec;
  return ostatniaSpacja ? ostatniaSpacja : koniec;
}

// rysuje linię od 'od' do 'doo' rozciągniętą na 'szer' pikseli (odstępy między słowami równo powiększone)
void rysujWyjustowane(int x, int y, uint32_t od, uint32_t doo, int szer) {
  int slow = 0, szerSlow = 0;
  for (uint32_t p = od; p < doo; ) {
    uint32_t k = p;
    while (k < doo && znak(k) != ' ') k++;
    if (k > p) { slow++; szerSlow += szerokosc(p, k); }
    p = k + 1;
  }
  int luz = szer - szerSlow;
  int przerw = slow - 1;
  for (uint32_t p = od; p < doo; ) {
    uint32_t k = p;
    while (k < doo && znak(k) != ' ') k++;
    if (k > p) {
      int w = szerokosc(p, k);
      u8g2Fonts.drawUTF8(x, y, wytnij(p, k));
      if (przerw > 0) {
        int odstep = luz / przerw;  // reszta pikseli rozkłada się na kolejne przerwy
        luz -= odstep;
        przerw--;
        x += w + odstep;
      }
    }
    p = k + 1;
  }
}

// skraca tekst (UTF-8) w buforze, aż zmieści się w 'szer' pikselach, i dopisuje "..."
// bufor musi mieć 4 bajty zapasu
void skroc(char* s, int szer) {
  if (u8g2Fonts.getUTF8Width(s) <= szer) return;
  int n = strlen(s);
  while (n > 0) {
    do n--; while (n > 0 && (s[n] & 0xC0) == 0x80);  // nie tnij w środku polskiej litery
    while (n > 0 && s[n - 1] == ' ') n--;
    strcpy(s + n, "...");
    if (u8g2Fonts.getUTF8Width(s) <= szer) return;
  }
}

// Układa jedną stronę zaczynając od miejsca 'start' w tekście.
// Gdy rysuj == true, także ją rysuje. Zwraca miejsce, od którego zaczyna się następna strona.
uint32_t ulozStrone(uint32_t start, bool rysuj) {
  uint32_t p = start;
  int y = GORA_TEKSTU;
  bool pierwszaNaStronie = true;

  while (p < DLUGOSC) {
    uint32_t poczatekLinii = p;
    while (poczatekLinii > 0 && znak(poczatekLinii - 1) != '\n') poczatekLinii--;
    uint32_t koniecLinii = p;
    while (koniecLinii < DLUGOSC && znak(koniecLinii) != '\n') koniecLinii++;
    uint32_t nastepnaLinia = koniecLinii < DLUGOSC ? koniecLinii + 1 : DLUGOSC;

    char z = znak(poczatekLinii);
    char typ = (z >= T_KSIEGA && z <= T_AKAPIT) ? z : T_ZWYKLY;
    uint32_t tresc = poczatekLinii + (typ ? 1 : 0);
    // w prozie każda linia bez znacznika to akapit (plik przygotowany starszą wersją strony)
    if (typ == T_ZWYKLY && proza) typ = T_AKAPIT;
    bool kontynuacja = p > tresc;  // dalsza część zawiniętej linii
    uint32_t powrot = kontynuacja ? p : poczatekLinii;
    if (!kontynuacja) p = tresc;

    // każdy rozdział od nowej strony
    if (typ == T_KSIEGA && !pierwszaNaStronie) return powrot;

    // pusta linia = odstęp (na górze strony pomijany)
    if (koniecLinii == tresc) {
      if (typ == T_SRODEK) y += 150;  // odstęp na stronie tytułowej
      else if (!pierwszaNaStronie && !proza) y += 10;  // w prozie akapity bez odstępów
      p = nastepnaLinia;
      continue;
    }

    ustawCzcionke(typ);
    int wznios = u8g2Fonts.getFontAscent();
    int zejscie = u8g2Fonts.getFontDescent();  // ujemne
    int przed = (typ == T_KSIEGA && !kontynuacja) ? 60 : 0;
    bool wysrodkuj = typ != T_ZWYKLY && typ != T_AKAPIT;

    int wciecie = 0;
    if (typ == T_ZWYKLY) {
      if (kontynuacja) wciecie = WCIECIE_ZAWINIECIA;
      else while (znak(p) == ' ') { p++; wciecie += WCIECIE_SPACJI; }
    } else if (typ == T_AKAPIT && !kontynuacja) {
      wciecie = WCIECIE_AKAPITU;
      while (znak(p) == ' ') p++;
    }

    int szer = display.width() - MARGINES - MARGINES_PRAWY - wciecie;
    uint32_t koniecKawalka = dopasuj(p, koniecLinii, szer);

    int linia = y + przed + wznios;  // linia bazowa tekstu
    if (linia - zejscie > dolTekstu && !pierwszaNaStronie) return powrot;

    if (rysuj) {
      int x = MARGINES + wciecie;
      if (wysrodkuj) x = MARGINES + (display.width() - MARGINES - MARGINES_PRAWY - szerokosc(p, koniecKawalka)) / 2;
      // w prozie wszystkie linie poza ostatnią w akapicie są wyjustowane
      if (typ == T_AKAPIT && koniecKawalka < koniecLinii) rysujWyjustowane(x, linia, p, koniecKawalka, szer);
      else u8g2Fonts.drawUTF8(x, linia, wytnij(p, koniecKawalka));
    }

    y = linia - zejscie + (typ == T_STRESZCZENIE ? 3 : 5);
    pierwszaNaStronie = false;

    if (koniecKawalka >= koniecLinii) {
      if (typ == T_KSIEGA) y += 8;
      else if (typ == T_PODTYTUL) y += 12;
      else if (typ == T_STRESZCZENIE) y += 14;
      p = nastepnaLinia;
    } else {
      p = koniecKawalka;
      while (p < koniecLinii && znak(p) == ' ') p++;
    }
  }
  return DLUGOSC;
}

void podzielNaStrony() {
  unsigned long t = millis();
  strony.clear();
  ksiegi.clear();
  pierwszaStronaKsiegi.clear();

  // Proza czy wiersz? W prozie większość tekstu jest w długich liniach (akapitach),
  // w wierszu linie to krótkie wersy.
  uint32_t wszystkie = 0, wDlugich = 0, poczatekLinii = 0;
  for (uint32_t i = 0; i < DLUGOSC; i++) {
    char z = znak(i);
    if (z == T_KSIEGA && i == poczatekLinii) ksiegi.push_back(i);
    if (z == '\n' || i == DLUGOSC - 1) {
      uint32_t dl = i - poczatekLinii;
      wszystkie += dl;
      if (dl > 120) wDlugich += dl;
      poczatekLinii = i + 1;
    }
  }
  proza = wDlugich > wszystkie / 2;

  uint32_t p = 0;
  while (p < DLUGOSC) {
    strony.push_back(p);
    uint32_t nastepna = ulozStrone(p, false);
    if (nastepna <= p) break;  // zabezpieczenie przed zapętleniem
    p = nastepna;
  }
  if (strony.empty()) strony.push_back(0);  // pusta książka

  // rozdziały zawsze zaczynają się od nowej strony, więc wystarczy znaleźć stronę z tym samym początkiem
  for (uint32_t k : ksiegi) {
    int s = 0;
    while (s < (int)strony.size() - 1 && strony[s + 1] <= k) s++;
    pierwszaStronaKsiegi.push_back(s);
  }

  Serial.printf("Stron: %d, rozdzialow: %d, %s, liczenie trwalo %lu ms\n",
                (int)strony.size(), (int)ksiegi.size(), proza ? "proza" : "wiersz", millis() - t);
}

// numer rozdziału, w którym jest strona (-1 = strona tytułowa)
int ksiegaStrony(int strona) {
  int k = -1;
  for (int i = 0; i < (int)pierwszaStronaKsiegi.size(); i++) {
    if (pierwszaStronaKsiegi[i] <= strona) k = i;
  }
  return k;
}

// --- zakładki ---

// klucz w Preferences (najwyżej 15 znaków), więc zamiast nazwy pliku jej skrót
String kluczZakladki(const String& plik) {
  uint32_t h = 2166136261u;
  for (const char* c = plik.c_str(); *c; c++) {
    h ^= (uint8_t)*c;
    h *= 16777619u;
  }
  char k[12];
  snprintf(k, sizeof(k), "z%08lx", (unsigned long)h);
  return k;
}

uint32_t zakladka(int ksiazka) {
  return pamiec.getUInt(kluczZakladki(ksiazki[ksiazka].plik).c_str(), 0);
}

// zakładki ze starej wersji, w której książki były wkompilowane w program
void przeniesStareZakladki() {
  const char* stare[] = {"pan_tadeusz.txt", "treny.txt"};
  for (int i = 0; i < 2; i++) {
    String k = "k" + String(i);
    if (!pamiec.isKey(k.c_str())) continue;
    pamiec.putUInt(kluczZakladki(stare[i]).c_str(), pamiec.getUInt(k.c_str(), 0));
    pamiec.remove(k.c_str());
  }
  if (pamiec.isKey("ostatnia")) {
    int o = pamiec.getInt("ostatnia", -1);
    if (o >= 0 && o < 2) pamiec.putString("ostatniPlik", stare[o]);
    pamiec.remove("ostatnia");
  }
}

// --- rysowanie ---

void rysujStrone(int strona) {
  ulozStrone(strony[strona], true);

  if (strona == 0) return;  // strona tytułowa bez stopki

  int W = display.width();
  int H = display.height();
  display.drawLine(MARGINES, H - 42, W - MARGINES_PRAWY, H - 42, GxEPD_BLACK);

  u8g2Fonts.setFont(u8g2_font_ncenR10_te);
  char numer[32];
  snprintf(numer, sizeof(numer), "%d / %d", strona, (int)strony.size() - 1);
  int szerNumeru = u8g2Fonts.getUTF8Width(numer);
  u8g2Fonts.drawUTF8(W - MARGINES_PRAWY - szerNumeru, H - 20, numer);

  int k = ksiegaStrony(strona);
  if (k >= 0) {
    uint32_t od = ksiegi[k] + 1;
    uint32_t doo = od;
    while (doo < DLUGOSC && znak(doo) != '\n') doo++;
    // długi tytuł rozdziału (np. w Lalce) skracamy, żeby nie wszedł na numer strony
    char rozdzial[200];
    strncpy(rozdzial, wytnij(od, min<uint32_t>(doo, od + 190)), sizeof(rozdzial));
    skroc(rozdzial, W - MARGINES - MARGINES_PRAWY - szerNumeru - 20);
    u8g2Fonts.drawUTF8(MARGINES, H - 20, rozdzial);
  }
}

void naSrodku(const char* tekst, int y) {
  u8g2Fonts.drawUTF8((display.width() - u8g2Fonts.getUTF8Width(tekst)) / 2, y, tekst);
}

void rysujStopke(const char* tekst) {
  int H = display.height();
  display.drawLine(MARGINES, H - 42, display.width() - MARGINES_PRAWY, H - 42, GxEPD_BLACK);
  u8g2Fonts.setFont(u8g2_font_ncenR10_te);
  naSrodku(tekst, H - 20);
}

// tytuł rozdziału 'k' razem z podtytułem, np. "Księga pierwsza - Gospodarstwo"
// (bufor musi mieć 4 bajty zapasu na skroc())
void tytulRozdzialu(int k, char* bufor, int rozmiarBufora) {
  uint32_t od = ksiegi[k] + 1;
  uint32_t doo = od;
  while (doo < DLUGOSC && znak(doo) != '\n') doo++;
  String t = wytnij(od, min<uint32_t>(doo, od + 150));

  uint32_t p = doo + 1;
  while (p < DLUGOSC && znak(p) == '\n') p++;
  if (p < DLUGOSC && znak(p) == T_PODTYTUL) {
    uint32_t koniec = p + 1;
    while (koniec < DLUGOSC && znak(koniec) != '\n') koniec++;
    t += " - ";
    t += wytnij(p + 1, min<uint32_t>(koniec, p + 1 + 100));
  }
  strlcpy(bufor, t.c_str(), rozmiarBufora - 4);
}
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
void loop() {
  if (ekran == WIFI) obsluzWifi();
  for (int i = 0; i < ILE_PRZYCISKOW; i++) {
    bool wcisniete = digitalRead(pinyPrzyciskow[i]) == LOW;
    if (wcisniete && !byloWcisniete[i]) {
      wcisnietyOd[i] = millis();
      ostatniaAktywnosc = millis();
      if (i != SRODEK) wcisnieto(i);  // MID działa dopiero po puszczeniu (krótko/długo)
    }
    if (i == SRODEK && wcisnietyOd[i]) {
      unsigned long trzymany = millis() - wcisnietyOd[i];
      if (wcisniete && trzymany >= DLUGIE_WCISNIECIE) uspij();
      if (!wcisniete) {
        wcisnietyOd[i] = 0;
        wcisnieto(i);
      }
    }
    byloWcisniete[i] = wcisniete;
  }
  // w trybie WiFi nie usypiamy, żeby nie przerwać wgrywania
  if (ekran != WIFI && millis() - ostatniaAktywnosc > USPIJ_PO) uspij();
  pilnujBaterii();
  delay(ekran == WIFI ? 2 : 20);
}

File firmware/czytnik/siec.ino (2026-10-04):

// Tryb WiFi: strona w przeglądarce do wgrywania książek i aktualizacji programu.
//
// Czytnik najpierw łączy się z domową siecią (ustawia się ją na stronie albo niżej w DOMOWA_SIEC).
// Jeśli jej nie ma albo się nie uda, tworzy własną sieć "Czytnik" (hasło "czytaj123").
// Wtedy działa jak hotelowe WiFi: telefon sam pokazuje stronę czytnika ("Zaloguj się do sieci").
// W trybie WiFi program można też wgrać z Arduino IDE: Narzędzia > Port > czytnik (port sieciowy).

#include <WiFi.h>
#include <WebServer.h>
#include <DNSServer.h>
#include <ESPmDNS.h>
#include <ArduinoOTA.h>
#include <Update.h>
#include "strona.h"

// Domowa sieć wpisana na stałe, np. "MojaSiec" i "haslo123".
// Sieć zapisana na stronie czytnika ma pierwszeństwo.
const char* DOMOWA_SIEC = "";
const char* DOMOWE_HASLO = "";

const char* NAZWA_W_SIECI = "czytnik";  // http://czytnik.local
const char* SIEC_CZYTNIKA = "Czytnik";
const char* HASLO_CZYTNIKA = "czytaj123";

WebServer serwer(80);
DNSServer dns;  // we własnej sieci każdy adres prowadzi do czytnika
bool trasyGotowe = false;
bool laczenie = false;       // na ekranie "Łączę z siecią..."
bool wlasnaSiec = false;     // true = czytnik zrobił własną sieć
String adres;                // adres IP pokazywany na ekranie
unsigned long restartO = 0;  // kiedy zrestartować po aktualizacji (0 = nie)

// wgrywanie książki
const char* TYMCZASOWY = "/k/.wgrywany";
File plikWgrywany;
String nazwaWgrywana;
uint32_t wgrano = 0;
String bladWgrywania;

// wgrywanie programu
String bladProgramu;

void wlaczWifi() {
  zamknijKsiazke();  // książki mogą się zmienić, po wyjściu wczytamy je od nowa
  ekran = WIFI;
  laczenie = true;
  odswiez(true);

  String ssid = pamiec.isKey("ssid") ? pamiec.getString("ssid", "") : DOMOWA_SIEC;
  String haslo = pamiec.isKey("ssid") ? pamiec.getString("haslo", "") : DOMOWE_HASLO;
  WiFi.setHostname(NAZWA_W_SIECI);
  wlasnaSiec = true;
  if (ssid.length()) {
    Serial.printf("Lacze z %s\n", ssid.c_str());
    WiFi.mode(WIFI_STA);
    WiFi.begin(ssid.c_str(), haslo.c_str());
    unsigned long start = millis();
    while (WiFi.status() != WL_CONNECTED && millis() - start < 15000) delay(100);
    wlasnaSiec = WiFi.status() != WL_CONNECTED;
  }
  if (wlasnaSiec) {
    WiFi.disconnect(true);
    WiFi.mode(WIFI_AP);
    WiFi.softAP(SIEC_CZYTNIKA, HASLO_CZYTNIKA);
    adres = WiFi.softAPIP().toString();
    dns.start(53, "*", WiFi.softAPIP());
  } else {
    adres = WiFi.localIP().toString();
  }
  Serial.printf("WiFi: http://%s\n", adres.c_str());

  if (!trasyGotowe) {
    ustawTrasy();
    trasyGotowe = true;
  }
  serwer.begin();
  ArduinoOTA.setHostname(NAZWA_W_SIECI);
  ArduinoOTA.begin();  // uruchamia też mDNS (czytnik.local)
  MDNS.addService("http", "tcp", 80);

  laczenie = false;
  odswiez(true);
}

void wylaczRadio() {
  ArduinoOTA.end();
  MDNS.end();
  dns.stop();
  serwer.stop();
  WiFi.disconnect(true);
  WiFi.mode(WIFI_OFF);
  Serial.println("WiFi wylaczone");
}

void wylaczWifi() {
  wylaczRadio();
  wczytajListe();
  pokazMenu();
}

void obsluzWifi() {
  if (wlasnaSiec) dns.processNextRequest();
  serwer.handleClient();
  ArduinoOTA.handle();
  obsluzGre();
  if (restartO && millis() > restartO) ESP.restart();
}

void rysujEkranWifi() {
  u8g2Fonts.setFont(u8g2_font_ncenB24_te);
  naSrodku("Tryb WiFi", 80);
  display.drawLine(MARGINES, 100, display.width() - MARGINES_PRAWY, 100, GxEPD_BLACK);

  int y = 170;
  if (laczenie) {
    u8g2Fonts.setFont(u8g2_font_ncenR14_te);
    naSrodku("Włączam WiFi...", y);
    return;
  }

  // ktoś gra w kółko i krzyżyk - zamiast instrukcji plansza
  if (graNaEkranie()) {
    u8g2Fonts.setFont(u8g2_font_ncenR12_te);
    naSrodku(("http://" + adres + "/gra").c_str(), 135);
    rysujGre(y);
    rysujStopke((String("Dowolny przycisk - wyjście      wersja ") + WERSJA).c_str());
    return;
  }

  if (wlasnaSiec) {
    u8g2Fonts.setFont(u8g2_font_ncenR14_te);
    naSrodku("Połącz telefon z siecią WiFi:", y);
    u8g2Fonts.setFont(u8g2_font_ncenB18_te);
    naSrodku(SIEC_CZYTNIKA, y + 40);
    u8g2Fonts.setFont(u8g2_font_ncenR14_te);
    naSrodku((String("hasło: ") + HASLO_CZYTNIKA).c_str(), y + 75);
  } else {
    u8g2Fonts.setFont(u8g2_font_ncenR14_te);
    naSrodku("Czytnik jest w sieci:", y);
    u8g2Fonts.setFont(u8g2_font_ncenB18_te);
    naSrodku(WiFi.SSID().c_str(), y + 40);
  }

  y += 160;
  u8g2Fonts.setFont(u8g2_font_ncenR14_te);
  naSrodku("Otwórz w przeglądarce:", y);
  u8g2Fonts.setFont(u8g2_font_ncenB18_te);
  naSrodku(("http://" + adres).c_str(), y + 45);
  u8g2Fonts.setFont(u8g2_font_ncenR12_te);
  naSrodku((String("albo http://") + NAZWA_W_SIECI + ".local").c_str(), y + 85);

  if (wlasnaSiec) {
    u8g2Fonts.setFont(u8g2_font_ncenR10_te);
    naSrodku("Telefon może sam pokazać stronę (\"Zaloguj się do sieci\").", y + 150);
    naSrodku("Jeśli strona się nie otwiera: wyłącz dane komórkowe,", y + 175);
    naSrodku("a gdy telefon zapyta o sieć bez internetu - zostań połączony.", y + 195);
    naSrodku("Na stronie możesz wpisać domową sieć WiFi,", y + 235);
    naSrodku("wtedy czytnik będzie łączył się z nią.", y + 255);
  }

  rysujStopke((String("Dowolny przycisk - wyjście      wersja ") + WERSJA).c_str());
}

// --- strona ---

void ustawTrasy() {
  serwer.on("/", HTTP_GET, []() {
    // bez tego przeglądarka potrafi pokazać starą stronę (ze starym przygotowywaniem książek)
    serwer.sendHeader("Cache-Control", "no-store");
    serwer.send_P(200, "text/html; charset=utf-8", STRONA);
  });
  serwer.on("/lista", HTTP_GET, wyslijListe);
  serwer.on("/wgraj", HTTP_POST, []() {
    if (bladWgrywania.length()) serwer.send(400, "text/plain; charset=utf-8", bladWgrywania);
    else serwer.send(200, "text/plain", "OK");
  }, odbierzKsiazke);
  serwer.on("/usun", HTTP_POST, usunKsiazke);
  serwer.on("/wifi", HTTP_POST, zapiszSiec);
  ustawTrasyGry();
  serwer.on("/aktualizuj", HTTP_POST, []() {
    if (bladProgramu.length() || Update.hasError() || !Update.isFinished()) {
      String b = bladProgramu.length() ? bladProgramu : String(Update.errorString());
      serwer.send(500, "text/plain; charset=utf-8", "Błąd aktualizacji: " + b);
    } else {
      serwer.send(200, "text/plain", "OK");
      restartO = millis() + 1000;
    }
  }, odbierzProgram);
  serwer.onNotFound([]() {
    // we własnej sieci telefon sprawdza internet (np. /generate_204) - odsyłamy go na stronę
    // czytnika, wtedy sam ją pokaże jako "logowanie do sieci"
    if (wlasnaSiec) {
      serwer.sendHeader("Location", "http://" + adres + "/");
      serwer.send(302, "text/plain", "");
    } else {
      serwer.send(404, "text/plain", "Nie ma");
    }
  });
}

String jsonTekst(const String& s) {
  String w = "\"";
  for (const char* c = s.c_str(); *c; c++) {
    if (*c == '"' || *c == '\\') w += '\\';
    if ((uint8_t)*c >= 32) w += *c;
  }
  return w + "\"";
}
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

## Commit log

2026-10-04 DIY e-book reader: ESP32-S3 firmware, Python book pipeline, web page and case
    [czytnik_eink.scad, czytnik_klapka.stl, czytnik_plytka.stl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]
2026-10-04 Reorganize repo to follow the architecture
    books/{source,prepared}, tools/ (prepare script + simulator),
    firmware/czytnik/ (sketch renamed to czytnik.ino), hardware/case/{stl,obj}.
    Update paths in scripts, tests and READMEs, and the .bin file name hint
    on the reader's upload page.
    [czytnik_eink.scad, czytnik_klapka.stl, czytnik_plytka.stl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]
2026-10-10 Show battery level and charging state in the library menu
    Battery voltage is read on GPIO1 and charger presence on GPIO2, both
    through 100k/100k dividers. The library menu shows the percentage or a
    lightning bolt while charging, and the reader goes to sleep when the
    battery drops below 3.3 V. Without the dividers nothing is shown.
2026-10-10 Document battery dividers, power path and the case layout
    Adds a guide for building the battery dividers, an interactive wiring
    drawing of the portrait layout (joystick in the back cover, charging
    port in the right wall, ESP32 at the bottom) and the PWR pin of newer
    HATs to both READMEs.
2026-10-10 Show the wiring layout on GitHub as SVG with a connection table
    The interactive HTML drawing did not render on GitHub. tools/okablowanie.py
    now generates docs/okablowanie.svg and docs/okablowanie.md (routing rules
    and connection table), and both READMEs embed the drawing.
2026-10-10 Show the wiring drawing directly in the README
    It was inside a collapsed section, so most visitors never saw it.
2026-10-20 Redesign the case around the measured parts
    Portrait layout that fits all the electronics behind the panel, with the
    image centred, a replaceable acrylic screen protector, flexure SET/RST keys
    under a leather recess, room for Dupont plugs beside the ESP and rounded
    edges. The scad now checks that no two boards overlap and is no longer
    mirrored. README shows the closed case and a labelled layout drawing.
2026-10-20 Rename the case preview so GitHub shows the new image
    GitHub's image proxy kept serving the cached podglad.png in the README.
2026-10-20 Add bottom screws and 3MF exports to the case
    Two M2 self-tapping screws in the bottom wall go into bosses on the back
    cover, like on a phone; the snaps stay. The parts are now also exported
    as 3MF, and the layout drawing marks the screws.
